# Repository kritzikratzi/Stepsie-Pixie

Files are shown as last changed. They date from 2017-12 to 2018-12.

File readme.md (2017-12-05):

<font color="red">WIP, please come back in a few weeks/months</font>

# Stepsie Pixie (WIP!)

This is a small project that combines: 

* stepper motor (to move your camera)
* relais (to trigger virtually any SLR camera)
* display+buttons (to adjust a few settings in place)
* esp8266 (as a controller, if things go well it'll also offer a web-ui)

The repository contains the code for the Arduino IDE and (soon) the eagle layout for making the board.

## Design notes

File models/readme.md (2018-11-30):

# 3D Models

**As always, work in progress**

This folder contains the 3d print models for stepsie pixie. You will need blender, openscad and a slicer tool of your choice to generate the STL and gcode files needed for printing. 

## Stepper to lego attachment 

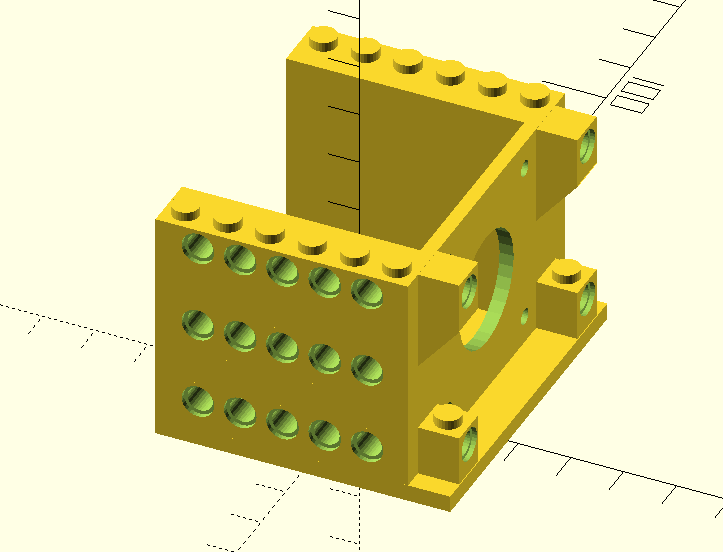
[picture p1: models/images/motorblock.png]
<br>
See `motorblock.scad`

A little attachement for a Nema-17 stepper with lots of oppertunities to connect to lego. 

## Tripod to lego attachment

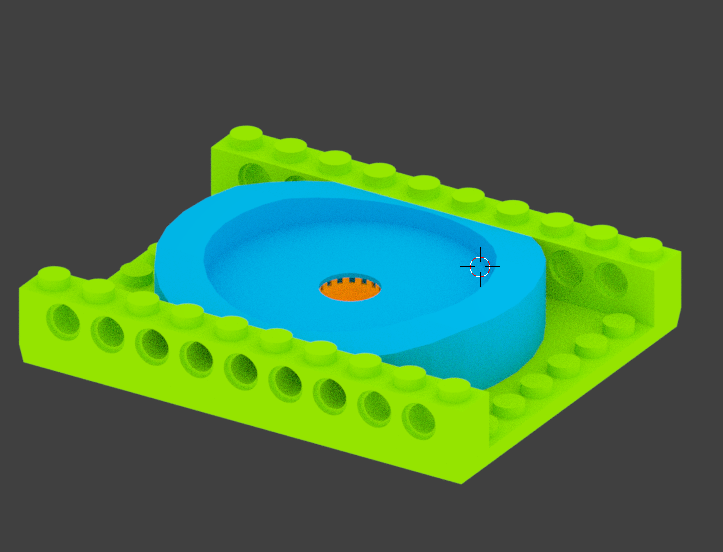
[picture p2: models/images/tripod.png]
<br>
See `tripod.6.blend`

A lego for an incredibly cheap but incredibly well built ball head tripod. 
https://www.amazon.de/Andoer-Kamera-Kugelkopf-Schnellwechselplatte-Schraube/dp/B00JSJXH3Q/

This also requires a large tripod screw to hold the tripod in place. 

## PCB Box (no lego attachment yet)

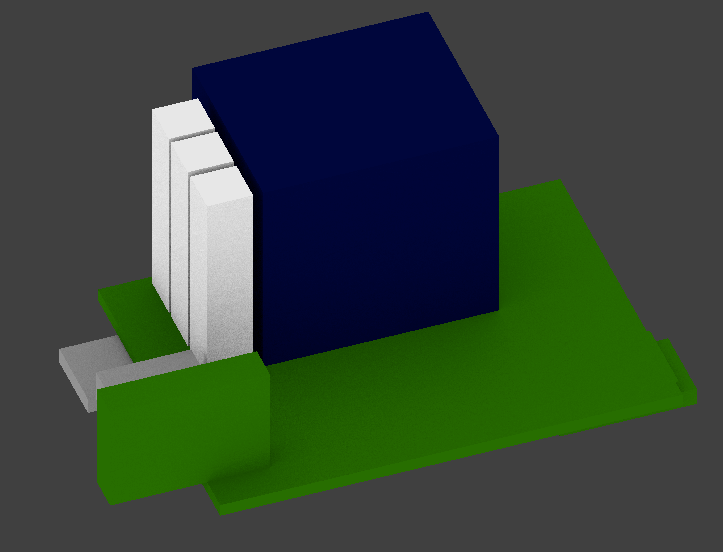
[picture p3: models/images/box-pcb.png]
<br>
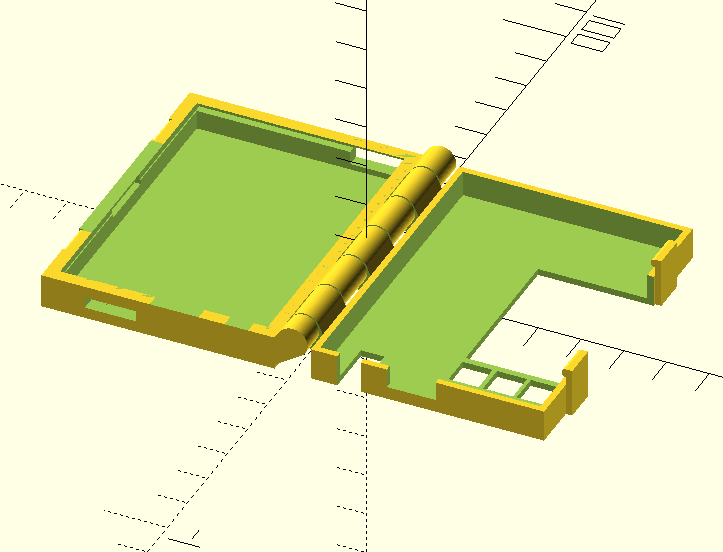
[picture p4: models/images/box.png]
<br>
* `Hinged_Box_asymtest.scad` The actual box. Print this! 
* `case.1.blend` Coarse layout of the PCB. I use this to make quick 2-layer prints to see if it fits in the real world. 
* `hinge-pcb.stl` STL export of the blender file. This is used in the openscad file to make lots of holes. 

## Library Credits

* Openscad lego library: https://github.com/cfinke/LEGO.scad (MIT License)
* Openscad hinged box: https://www.thingiverse.com/thing:82533 (CC-BY-NC)

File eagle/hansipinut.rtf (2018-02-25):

Buttons
D5
D6
D7

Stepper
D3 =
D4
D8
D9

D10 => Trigger WRONG

PINS vom OLED ESP:
d3 =IO0
d4 = IO2
d8 = IO15
d9 = rxd = GPIO3
d10 = txd = GPIO1

up=GPIO13 auf gnd = D7
down = GPIO12 auf gnd = D6
press = GPIO14 = D5

Wir brauchen:
- 3 Inputs f. Buttons
- 4 Out für Stepper
- 1 Out ENA
- 1 Out Trigger

Probieren wir mal:
GPIO0 = S1 => D3 OK
GPIO2 = S2 => D4? => Darf offenbar kein IN sein… => D10 mit int. Pullup OK
ADC = S3 OK

Dann bleiben:
GPIO12 = D6 = Stepper
GPIO13 = D7 = Stepper
GPIO3 = RXD = D9 = Stepper = Wie vorher
GPIO1 = TXD = D10 = Relais verkehrt rum => machma mal D4 draus
GPIO14 = D5 = Stepper
GPIO15 = D8 den machma zu Stepper enable

stepper alt zu neu
D3 = D5 = rxd hat pullup!
D4 = D6 = gpio12
D8 = D7 = GPIO13
D9 = D9 gleich = 4a?

ADC als Input verwenden????
txd darf nicht pulldown@boot

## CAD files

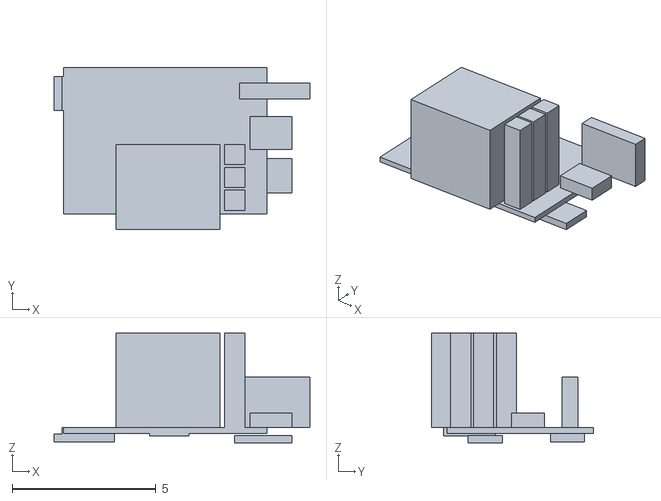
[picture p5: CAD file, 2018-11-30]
models/hinge-pcb.stl
8.92 x 5.63 x 3.83

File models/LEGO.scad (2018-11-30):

/**
 * Derived from http://www.thingiverse.com/thing:5699
 *
 * LEGO®, the LEGO® logo, the Brick, DUPLO®, and MINDSTORMS® are trademarks of the LEGO® Group. ©2012 The LEGO® Group.
 */

/* [General] */

// Width of the block, in studs
block_width = 2;

// Length of the block, in studs
block_length = 6;

// Height of the block. A ratio of "1" is a standard LEGO brick height; a ratio of "1/3" is a standard LEGO plate height; "1/2" is a standard DUPLO plate.
block_height_ratio = 1; // [.33333333333:1/3, .5:1/2, 1:1, 2:2, 3:3, 4:4, 5:5, 6:6, 7:7, 8:8, 9:9, 10:10]

// What type of block should this be? For type-specific options, see the "Wings," "Slopes," "Curves", and "Baseplates" tabs.
block_type = "brick"; // [brick:Brick, tile:Tile, wing:Wing, slope:Slope, curve:Curve, baseplate:Baseplate]

// What brand of block should this be? LEGO for regular LEGO bricks, Duplo for the toddler-focused larger bricks.
block_brand = "lego"; // [lego:LEGO, duplo:DUPLO]

// What stud type do you want? Hollow studs allow rods to be pushed into the stud.
stud_type = "solid"; // [solid:Solid, hollow:Hollow]

// Should the block include round horizontal holes like the Technics LEGO bricks have?
technic_holes = "no"; // [no:No, yes:Yes]

// Should the block include vertical cross-shaped axle holes?
vertical_axle_holes = "no"; // [no:No, yes:Yes]

/* [Wings] */

// What type of wing? Full is suitable for the front of a plane, left/right are for the left/right of a plane.
wing_type = "full"; // [full:Full, left:Left, right:Right]

// The number of studs across the end of the wing. If block_width is odd, this needs to be odd, and the same for even.
wing_end_width = 2;

// The length of the rectangular portion of the wing, in studs.
wing_base_length = 3;

// Should the wing edges be notched to accept studs below?
wing_stud_notches = "yes"; // [yes:Yes, no:No]

/* [Slopes] */

// How many rows of studs should be left before the slope?
slope_stud_rows = 1;

// How much vertical height should be left at the end of the slope? e.g, a value of zero means the slope reaches the bottom of the block. A value of 1 means that for a block with height 2, the slope reaches halfway down the block.
slope_end_height = 0;

/* [Curves] */

// How many rows of studs should be left before the curve?
curve_stud_rows = 5;

// Should the curve be convex or concave?
curve_type = "concave"; // [concave:Concave, convex:Convex]

// How much vertical height should be left at the end of the curve? e.g, a value of zero means the curve reaches the bottom of the block. A value of 1 means that for a block with height 2, the curve reaches halfway down the block.
curve_end_height = 0;

/* [Baseplates] */

// If you want a roadway, how wide should it be (in studs)? A roadway is a smooth (non-studded) section of a baseplate.
roadway_width = 0;

// How long should the roadway be?
roadway_length = 0;

// Where should the roadway start (x-value)? A value of zero puts the roadway at the far left side of the plate.
roadway_x = 0;

// Where should the roadway start (y-value)? A value of zero puts the roadway at the front of the plate.
roadway_y = 0;

/* [SNOT] */

// SNOT means Studs Not On Top -- bricks with alternative stud configurations.
// Put studs on the top and buttom?
dual_sided = "no"; // [no:No, yes:Yes]

// Instead of both sides having studs, both sides can have no studs.
dual_bottom = "no"; // [no:No, yes:Yes]

/* [Printer-Specific] */

// Should extra reinforcement be included to make printing on an FDM printer easier? Ignored for tiles, since they're printed upside-down and don't need the reinforcement. Recommended for block heights less than 1 or for Duplo bricks. 
use_reinforcement = "no"; // [no:No, yes:Yes]

// If your printer prints the blocks correctly except for the stud diameter, use this variable to resize just the studs for your printer. A value of 1.05 will print the studs 105% wider than standard.
stud_rescale=1.05;
//stud_rescale = 1.0475 * 1; // Orion Delta, T-Glase
//stud_rescale = 1.022 * 1; // Orion Delta, ABS

// Print tiles upside down.
translate([0, 0, (block_type == "tile" ? block_height_ratio * block_height : 0)]) rotate([0, (block_type == "tile" ? 180 : 0), 0]) {
    block(
        width=block_width,
        length=block_length,
        height=block_height_ratio,
        type=block_type,
        brand=block_brand,
        stud_type=stud_type,
        horizontal_holes=(technic_holes=="yes"),
        vertical_axle_holes=(vertical_axle_holes=="yes"),
        reinforcement=(use_reinforcement=="yes"),
        wing_type=wing_type,
        wing_end_width=wing_end_width,
        wing_base_length=wing_base_length,
        stud_notches=(wing_stud_notches=="yes"),
        slope_stud_rows=slope_stud_rows,
        slope_end_height=slope_end_height,
        curve_stud_rows=curve_stud_rows,
        curve_type=curve_type,
        curve_end_height=curve_end_height,
        roadway_width=roadway_width,
        roadway_length=roadway_length,
        roadway_x=roadway_x,
        roadway_y=roadway_y,
        stud_rescale=stud_rescale,
        dual_sided=(dual_sided=="yes"),
        dual_bottom=(dual_bottom=="yes")
    );
}

module block(
    width=1,
    length=2,
    height=1,
    type="brick",
    brand="lego",
    stud_type="solid",
    horizontal_holes=false,
    vertical_axle_holes=false,
    reinforcement=false,
    wing_type="full",
    wing_end_width=2,
    wing_base_length=2,
    stud_notches=false,
    slope_stud_rows=1,
    slope_end_height=0,
    curve_stud_rows=1,
    curve_type="concave",
    curve_end_height=0,
    roadway_width=0,
    roadway_length=0,
    roadway_x=0,
    roadway_y=0,
    stud_rescale=stud_rescale,
    dual_sided=false,
    dual_bottom=false
    ) {
    post_wall_thickness = (brand == "lego" ? 0.85 : 1);
    wall_thickness=(brand == "lego" ? 1.45 : 1.5);
    stud_diameter=(brand == "lego" ? 4.85 : 9.35);
    hollow_stud_inner_diameter = (brand == "lego" ? 3.1 : 6.7);
    stud_height=(brand == "lego" ? 1.8 : 4.4);
    stud_spacing=(brand == "lego" ? 8 : 8 * 2);
    block_height=(brand == "lego" ? (type == "baseplate" ? 1.3 : 9.6) : 9.6 * 2);
    pin_diameter=(brand == "lego" ? 3 : 3 * 2);
    post_diameter=(brand == "lego" ? 6.5 : 13.2);
    cylinder_precision=(brand == "lego" ? 0.1 : 0.05);
    reinforcing_width = (brand == "lego" ? 0.7 : 1);

    spline_length = (brand == "lego" ? 0.25 : 1.7);
    spline_thickness = (brand == "lego" ? 0.7 : 1.3);

    horizontal_hole_diameter = (brand == "lego" ? 4.8 : 4.8 * 2);
    horizontal_hole_z_offset = (brand == "lego" ? 5.8 : 5.8 * 2);
    horizontal_hole_bevel_diameter = (brand == "lego" ? 6.2 : 6.2 * 2);
    horizontal_hole_bevel_depth = (brand == "lego" ? 0.9 : 0.9 * 1.5 / 1.2 );

    roof_thickness = (type == "baseplate" || dual_sided ? block_height * height : 1 * 1);

    // Brand-independent measurements.
    axle_spline_width = 2.0;
    axle_diameter = 5 * 1;
    wall_play = 0.1 * 1;
    horizontal_hole_wall_thickness = 1 * 1;

    // Ensure that width is always less than or equal to length.
//hansi:
    real_width = width;
    real_length = length;

//    real_width = (type == "wing" ? width : min(width, length) );
//    real_length = (type == "wing" ? length : max(width, length) );
    real_height = max((type == "baseplate" ? 1 : 1/3), height);

    // Ensure that the wing end width is even if the width is even, odd if odd, and a reasonable value.
    real_wing_end_width = (wing_type == "full"
        ?
        min(real_width - 2, ((real_width % 2 == 0) ? 
            (max(2, (
                wing_end_width % 2 == 0 ?
                (wing_end_width)
                :
                (wing_end_width-1)
            )))
            :
            (max(1, (
                wing_end_width % 2 == 0 ?
                (wing_end_width-1)
                :
                (wing_end_width)
            )))
        ))
        :
        (min(real_width-1, max(1, wing_end_width))) // Half-wing
    );

    // Ensure that the base length is a reasonable value.
    real_wing_base_length = min(real_length-1, max(1, wing_base_length)) + 1; // +1 because the angle starts before the last stud.
        
    // Validate all the rest of the arguments.
    real_slope_end_height = max(0, min(real_height - 1/3, slope_end_height));
    real_slope_stud_rows = min(real_length - 1, slope_stud_rows);
    real_curve_stud_rows = max(0, curve_stud_rows);
    real_curve_type = (curve_type == "convex" ? "convex" : "concave");
    real_curve_end_height = max(0, min(real_height - 1/3, curve_end_height));
    real_horizontal_holes = horizontal_holes && ((type == "baseplate" && real_height >= 8) || real_height >= 1) && !dual_sided;
    real_vertical_axle_holes = vertical_axle_holes && real_width > 1;
    real_reinforcement = reinforcement && type != "baseplate" && type != "tile" && !dual_sided;
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

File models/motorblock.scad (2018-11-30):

use <LEGO.scad>;

le=8;
lh=9.6;

rotate([0, 0, 180]) union() {
    scale([le,le,lh]){
        translate([-3+1/6,-0.015,3+1/6]) difference(){
            cube([1/3,6+0.03,4+1/3],true);
            scale([1/le,1/le,1/lh]) union(){
                rotate([0,90,0]) cylinder(h=10, d=22, center=true, $fn=32);
                rotate([0,90,0]) translate([ 41/2-5,-41/2+5,0]) cylinder(h=10, d=3, center=true, $fn=32);
                rotate([0,90,0]) translate([-41/2+5, 41/2-5,0]) cylinder(h=10, d=3, center=true, $fn=32);
                rotate([0,90,0]) translate([-41/2+5,-41/2+5,0]) cylinder(h=10, d=3, center=true, $fn=32);
                rotate([0,90,0]) translate([ 41/2-5, 41/2-5,0]) cylinder(h=10, d=3, center=true, $fn=32);
            }
        }
        
         translate([-3,3.5-0.025,3+1/3]) rotate([-90,180,90]) color("orange")  prism(1-0.025, 1, 1);
         translate([-3,-2.54+0.015,3+1/3]) rotate([-90,180,90]) color("orange")  prism(1-0.025, 1, 1);
    };
    
    delta=3*le-42/2;
    length=(6-1/3)*le-0.2;
    translate([(-3+1/3)*le,42/2,lh]) color("black") cube([length,delta,(4+1/3)*lh], center=false);
    translate([(-3+1/3)*le,-42/2-delta-0.2,lh]) color("black") cube([length,delta,(4+1/3)*lh], center=false);
    
    color( "blue" ) place(0, -0.5, 2/3) uncenter(0, 0) block(
      width=8,
      length=7,
      roadway_width=8,
      roadway_length=7,
      height=1/3,
      reinforcement="yes"
     );

    color( "red" ) place(3, -3.5+0.02, 1) uncenter(0, 0)  rotate([0,0,90]) block(
      width=1,
      length=1,
      height=1,
      horizontal_holes=true,
      reinforcement="yes"
);
    color( "red" ) place(3, -3.5+0.02, 4+1/3) uncenter(0, 0)  rotate([0,0,90]) block(
      width=1,
      length=1,
      height=1,
      horizontal_holes=true,
      reinforcement="yes",
      roadway_width=1, 
      roadway_length=1
     );
    color( "red" ) place(-3, -3.5+0.02, 1) uncenter(0, 0) rotate([0,0,90]) block(
      width=1,
      length=1,
      height=1,
      horizontal_holes=true,
      reinforcement="yes"
     );
    color( "red" ) place(-3, -3.5+0.02, +4+1/3) uncenter(0, 0) rotate([0,0,90]) block(
      width=1,
      length=1,
      height=1,
      horizontal_holes=true,
      reinforcement="yes",
      roadway_width=1, 
      roadway_length=1
     );

    
    for(b=[0,1]){
        place(-7*b,0) union(){
            for(x=[0:2]){
                color( "green") place(3.5, 0, 1+x*5/3) uncenter(0, 0) block(
                    width=1,
                    length=6,
                    height=1,
                    horizontal_holes=true
                );
            }
            for(y=[0:1]){
                color( "blue" ) place(3.5, 0, 2+5/3*y) uncenter(0, 0) block(
                    width=1,
                    length=6,
                    height=2/3,
                    horizontal_holes=true
                );
            }
        }
    };
   // }
}

   module prism(l, w, h){
       polyhedron(
               points=[[0,0,0], [l,0,0], [l,w,0], [0,w,0], [0,w,h], [l,w,h]],
               faces=[[0,1,2,3],[5,4,3,2],[0,4,5,1],[0,3,4],[5,2,1]]
               );
       }

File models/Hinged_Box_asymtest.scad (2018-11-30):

$fn = 100;
width = 54.5;
height = 7;
asym=1;
depth = 74.5;
wallThickness = 1.5;
hingeOuter = 6.5;
hingeInner = 3.5;
hingeInnerSlop = .4;
hingeFingerSlop = .4;
fingerLength = hingeOuter/1.65;
fingerSize = 12;
topFingerSize = fingerSize;
pos = -depth/2;
latchWidth = 8;
lift=0;
z = 0;

top_final_ani();
bottom_final();
//top();
//pcb();
//bottom(); 

module top_final_ani(){
    translate([0,0,height]){
        r = max(0, min(1, ($t*1.4-0.2)));
        rotate([0,-r*180,0]){
            translate([0,0,-height]){
                top_final(); 
            }
        }
    }
}
module top_final(){
    difference(){
        top(); 
        translate([0,0,height+0*asym]){
            rotate([0,180,0]){
                translate([0,0,-height]){
                    pcb(); 
                }
            }
        }
   }
} 

module bottom_final(){
    difference(){
        bottom(); 
        pcb();
    }
}

module pcb(){
    translate([-31,-0.85,5+asym]){
        rotate([0,0,-90]){
            scale([10,10,10]){
                color([1,0,0])
                import("hinge-pcb.stl", convexity=5);
            }
        }
    }
}


module bottom() {
    h2=height+asym;
	union() {
		// main box and cutout
		difference() {
			translate([-width - fingerLength, -depth/2, 0]) {
				cube([width,depth,h2]);
			}
            
/*			translate([(-width - fingerLength) + wallThickness, -depth/2 + wallThickness, wallThickness]) {
				cube([width - (wallThickness * 2), depth - (wallThickness * 2), height]);
			}*/
            
            translate([(-width - fingerLength) + wallThickness*2, -depth/2 + wallThickness*2, wallThickness]) {
				cube([width - (wallThickness * 4), depth - (wallThickness * 4), height]);
			}


             for(i = [-1 : 2: 1]){
                 dy = i*depth*0.3;
                 translate([0,dy,0]){

                    // latch cutout
                    translate([-width - fingerLength - 0.05, (-latchWidth/2) - (hingeFingerSlop/2), wallThickness]) {
                        cube([wallThickness/2 + .1, latchWidth + hingeFingerSlop, height]);
                    }
                }
            }
			
		}

         for(i = [-1 : 2: 1]){
             dy = i*depth*0.3;
             translate([0,dy,0]){

                //latch cylinder
                difference() {
                    translate([-width - fingerLength + (wallThickness/1.5), -latchWidth/2, h2 - 1]) {
                        rotate([-90,0,0]) {
                            color([0,1,0]) cylinder(r = 1, h = latchWidth);
                        }
                    }
                    // front wall wipe
                    translate([-width - fingerLength+1, -depth/2,0]) {
                        color([1,0,0]) cube([5,depth,h2]);
                    }
                }
            }
        }
        
		difference() {
			hull() {
				translate([0,-depth/2,height]) {
					rotate([-90,0,0]) {
						cylinder(r = hingeOuter/2, h = depth);
					}
				}
				translate([-fingerLength - .1, -depth/2,height - hingeOuter]){
					cube([.1,depth,hingeOuter]);
				}
				translate([-fingerLength, -depth/2,height-.1]){
					cube([fingerLength,depth,.1]);
				}
				translate([0, -depth/2,height]){
					rotate([0,45,0]) {
						cube([hingeOuter/2,depth,.01]);
					}
				}
			}
			// finger cutouts

			for  (i = [-depth/2 + fingerSize:fingerSize*2:depth/2]) {
				translate([-fingerLength,i - (fingerSize/2) - (hingeFingerSlop/2),0]) {
					cube([fingerLength*2,fingerSize + hingeFingerSlop,height*2]);
				}
			}
		}

		// center rod
		translate([0, -depth/2, height]) {
			rotate([-90,0,0]) {
				cylinder(r = hingeInner /2, h = depth);
			}
		}
	}
}

module top() {
    h2=height-asym;
	union() {
		difference() {
			translate([fingerLength, -depth/2, 0]) {
				cube([width,depth,h2 - .5]);
			}
	
			translate([fingerLength + wallThickness, -depth/2 + wallThickness, wallThickness]) {
				cube([width - (wallThickness * 2), depth - (wallThickness * 2), h2]);
			}

			
		}

		//latch
         for(i = [-1 : 2: 1]){
             dy = i*depth*0.3;
             translate([0,dy,0]){
                translate([width + fingerLength - 0*wallThickness - 0*1.5, (-latchWidth/2), 0]) {
                    color([0,1,0])
                    cube([1.5, latchWidth, h2 - .5 + 4]);
                }
                translate([width + fingerLength - 0*wallThickness, -latchWidth/2, h2 - .5 + 3]) {
                    rotate([-90,0,0]) {
                        cylinder(r = 1, h = latchWidth);
                    }
                }
            }
        }

		difference() {
			hull() {
				translate([0,-depth/2,height]) {
					rotate([-90,0,0]) {
						cylinder(r = hingeOuter/2, h = depth);
					}
				}
				translate([fingerLength, -depth/2,height - hingeOuter - .5]){
					cube([.1,depth,hingeOuter - .5]);
				}
				translate([-fingerLength/2, -depth/2,height-.1]){
					cube([fingerLength,depth,.1]);
				}
				translate([0, -depth/2,height]){
					rotate([0,45,0]) {
						cube([hingeOuter/2,depth,.01]);
					}
				}
			}
			// finger cutouts
			for  (i = [-depth/2:fingerSize*2:depth/2 + fingerSize]) {
				translate([-fingerLength,i - (fingerSize/2) - (hingeFingerSlop/2),0]) {
					cube([fingerLength*2,fingerSize + hingeFingerSlop,height*2]);
				}
				if (depth/2 - i < (fingerSize * 1.5)) {
					translate([-fingerLength,i - (fingerSize/2) - (hingeFingerSlop/2),0]) {
						cube([fingerLength*2,depth,height*2]);
					}
				}
			}

			// center cutout
			translate([0, -depth/2, height]) {
				rotate([-90,0,0]) {
					cylinder(r = hingeInner /2 + hingeInnerSlop, h = depth);
				}
			}
		}
	}
    
    dh=h2-0.5-wallThickness;
    translate([width/2,0,wallThickness]){
        color([1,0,0]) translate([24,-31.5,0]) cylinder(h=dh,r=3);
        color([1,0,1]) translate([24, 31.5,0]) cylinder(h=dh,r=3);
        color([0,1,0]) translate([-14,-19,0]) cylinder(h=dh,r=3);
        color([0,0,1]) translate([-14, 19,0]) cylinder(h=dh,r=3);
    }
}

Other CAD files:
models/case.1.blend
models/tripod6.blend

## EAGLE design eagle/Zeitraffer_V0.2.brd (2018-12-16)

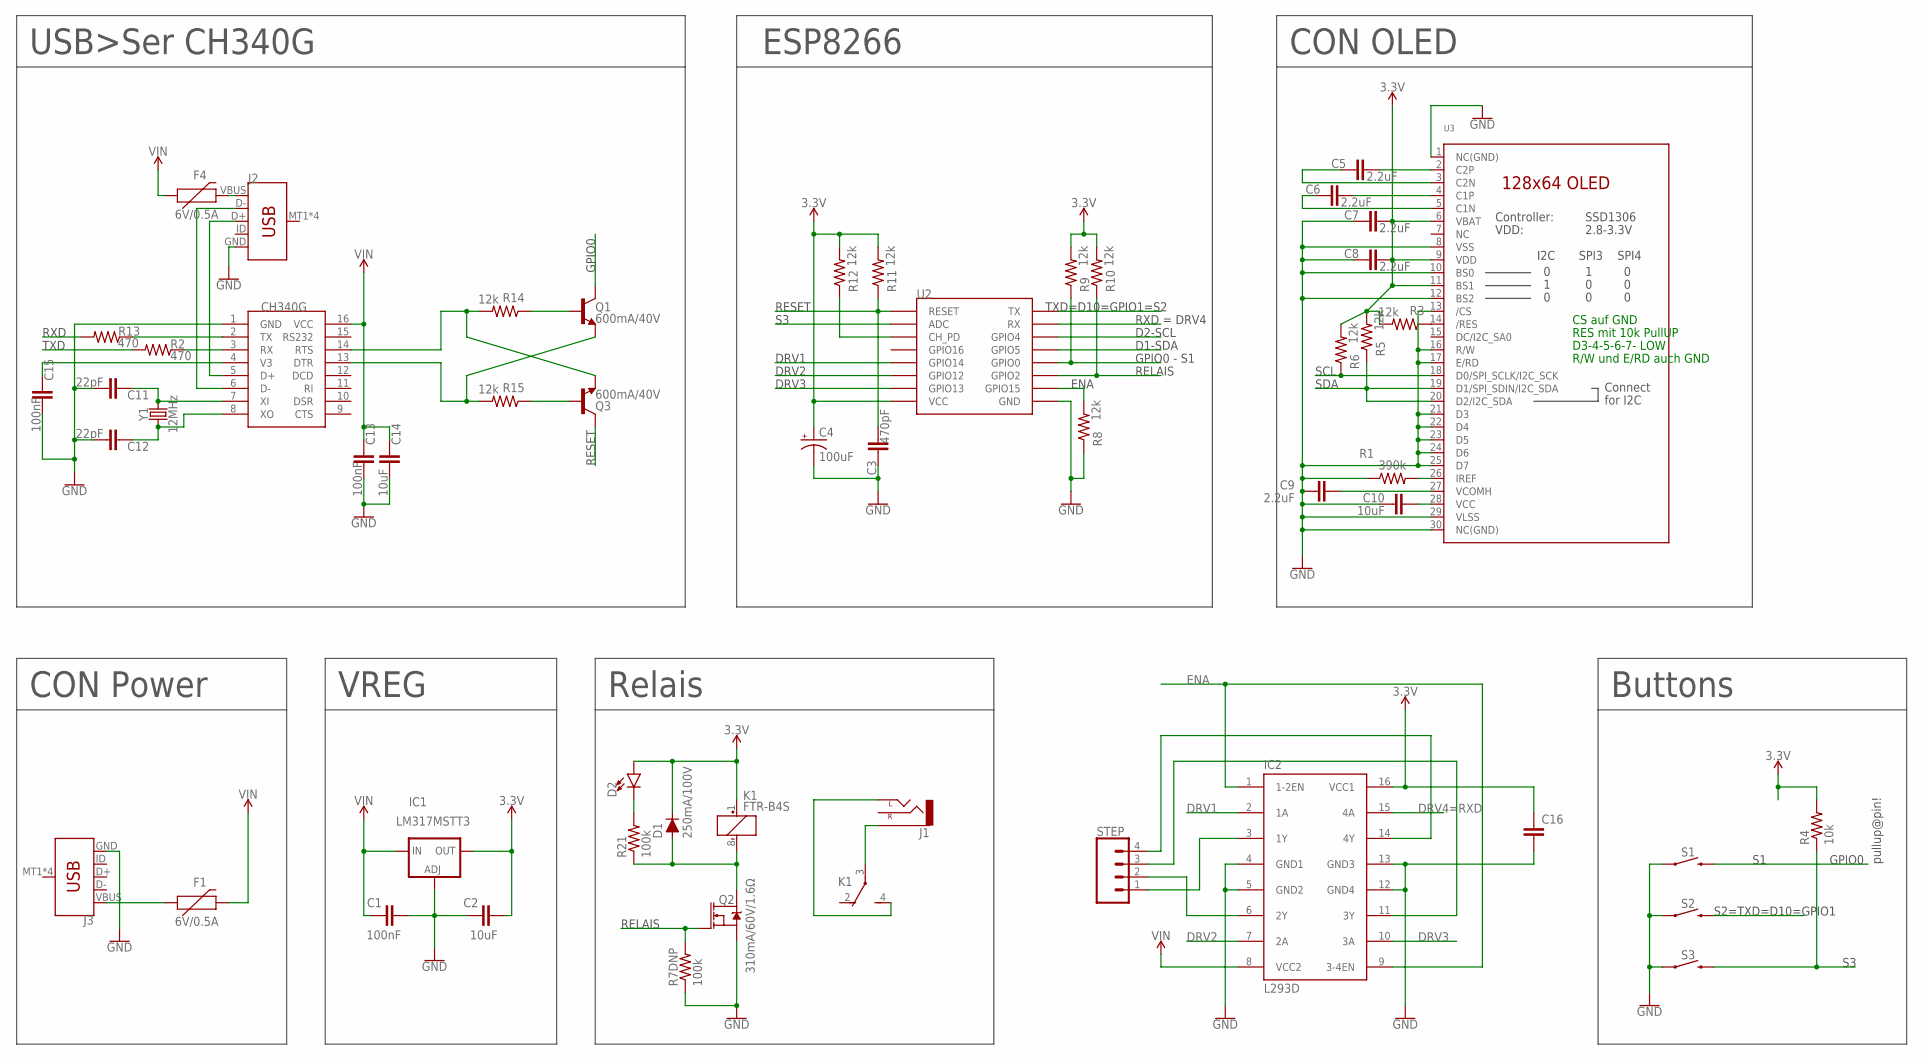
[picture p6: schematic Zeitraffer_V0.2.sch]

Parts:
C1, C13, C15: 100nF; 0805
C2, C10, C14: 10uF; 0805
C3: 470pF; 0805
C4: 100uF; EIA7343
C5, C6, C7, C8, C9: 2.2uF; 0805
C11, C12: 22pF; 0805
C16: C-EUC0805; C0805
D1: 250mA/100V; SOD-323
D2: LED1206-BOTTOM; LED-1206-BOTTOM
F1, F4: 6V/0.5A; 1206
IC1: LM317MSTT3; SOT223
IC2: L293D; DIL16
J1: AUDIO_JACK_2.5MM_2.5MM; STEREOJACK2.5MM_STEREOJACK2.5MM
J2, J3: USB_MICRO-B_SMT; USB-MICROB
K1: FTR-B4S
Q1, Q3: 600mA/40V; SOT23-3
Q2: 310mA/60V/1.6Ω; SOT323
R1: 390k; 0805
R2, R13: 470; 0603
R3, R5, R6, R8, R9, R10, R11, R12, R14, R15: 12k; R0805
R4: 10k; R0805
R7DNP, R21: 100k; R0805
S1, S2, S3: MOMENTARY-SWITCH-SPST-PTH-6.0MM; TACTILE_SWITCH_PTH_6.0MM
STEP: CONN_04JST-PTH; JST-4-PTH
U2: ESP12SMD; ESP12-SMD
U3: DISP_OLED_UG-2864HSWEG01; UG-2864HSWEG01_1.3_WRAPAROUND
U$2: CH340G; SOIC16
Y1: 12MHz; CRYSTAL-SMD-5X3.2-4PAD

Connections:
3.3V: C2.2, C4.A (+), C7.2, C8.2, C16.1, D1.C, D2.A, IC1.4 (OUT), IC2.16 (VCC1), K1.1 (+), R3.2, R4.2, R5.2, R6.2, R9.2, R10.2, R11.2, R12.2, U2.VCC, U3.6 (VBAT), U3.9 (VDD), U3.11 (BS1)
DRV1: IC2.2 (1A), U2.GPIO14
DRV2: IC2.7 (2A), U2.GPIO12
DRV3: IC2.10 (3A), U2.GPIO13
ENA: IC2.1 (1-2EN), IC2.9 (3-4EN), R8.2, U2.GPIO15
GND: C1.2, C2.1, C3.1, C4.C (-), C7.1, C8.1, C9.1, C10.1, C11.2, C12.2, C13.2, C14.2, C15.2, C16.2, IC1.1 (ADJ), IC2.4 (GND1), IC2.5 (GND2), IC2.12 (GND4), IC2.13 (GND3), J2.GND, J3.GND, Q2.2 (S), R1.1, R7DNP.1, R8.1, S1.1, S2.1, S3.1, U2.GND, U3.1 (NC(GND)), U3.8 (VSS), U3.10 (BS0), U3.12 (BS2), U3.13 (/CS), U3.16 (R/W), U3.17 (E/RD), U3.21 (D3), U3.22 (D4), U3.23 (D5), U3.24 (D6), U3.25 (D7), U3.29 (VLSS), U3.30 (NC(GND)), U$2.1 (GND)
GPIO0: Q1.3 (C), R9.1, S1.3 (2), U2.GPIO0
unnamed: F1.1, J3.VBUS
unnamed: J1.RING1 (SLEEVE), K1.3
unnamed: D1.A, K1.8 (-), Q2.3 (D), R21.1
unnamed: J1.SHIELD (LEFT), K1.4 (S)
unnamed: C5.2, U3.2 (C2P)
unnamed: C6.2, U3.4 (C1P)
unnamed: C5.1, U3.3 (C2N)
unnamed: C6.1, U3.5 (C1N)
unnamed: R1.2, U3.26 (IREF)
unnamed: C9.2, U3.27 (VCOMH)
unnamed: C10.2, U3.28 (VCC)
unnamed: R3.1, U3.14 (/RES)
unnamed: C11.1, U$2.7 (XI), Y1.3 (2)
unnamed: R12.1, U2.CH_PD
unnamed: C12.1, U$2.8 (XO), Y1.1
unnamed: J2.D+, U$2.5 (D+)
unnamed: J2.D-, U$2.6 (D-)
unnamed: Q3.2 (E), R14.2, U$2.14 (RTS)
unnamed: Q1.2 (E), R15.2, U$2.13 (DTR)
unnamed: R13.1, U$2.2 (TX)
unnamed: R2.1, U$2.3 (RX)
unnamed: C15.1, U$2.4 (V3)
unnamed: Q3.1 (B), R15.1
unnamed: Q1.1 (B), R14.1
unnamed: IC2.3 (1Y), STEP.1
unnamed: IC2.6 (2Y), STEP.2
unnamed: F4.2, J2.VBUS
unnamed: D2.C, R21.2
unnamed: IC2.14 (4Y), STEP.4
unnamed: IC2.11 (3Y), STEP.3
RELAIS: Q2.1 (G), R7DNP.2, R10.1, U2.GPIO2
RESET: C3.2, Q3.3 (C), R11.1, U2.RESET
RXD: IC2.15 (4A), R13.2, U2.RXD0 (RX)
S3: R4.1, S3.3 (2), U2.ADC
SCL: R6.1, U2.GPIO4, U3.18 (D0/SPI_SCLK/I2C_SCK)
SDA: R5.1, U2.GPIO5, U3.19 (D1/SPI_SDIN/I2C_SDA), U3.20 (D2/I2C_SDA)
TXD: R2.2, S2.3 (2), U2.TXD0 (TX)
VIN: C1.1, C13.1, C14.1, F1.2, F4.1, IC1.3 (IN), IC2.8 (VCC2), U$2.16 (VCC)

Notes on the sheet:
SCL
SDA
CON OLED
VREG
S2=TXD=D10=GPIO1
Buttons
CON Power
RELAIS
Relais
TXD=D10=GPIO1=S2
RXD = DRV4
GPIO0 - S1
RESET
D1-SDA
D2-SCL
GPIO0
pullup@pin!
DRV2
DRV3
DRV1
ESP8266
TXD
RXD
USB>Ser CH340G
ENA
DRV4=RXD
CS auf GND
RES mit 10k PullUP
D3-4-5-6-7- LOW
R/W und E/RD auch GND

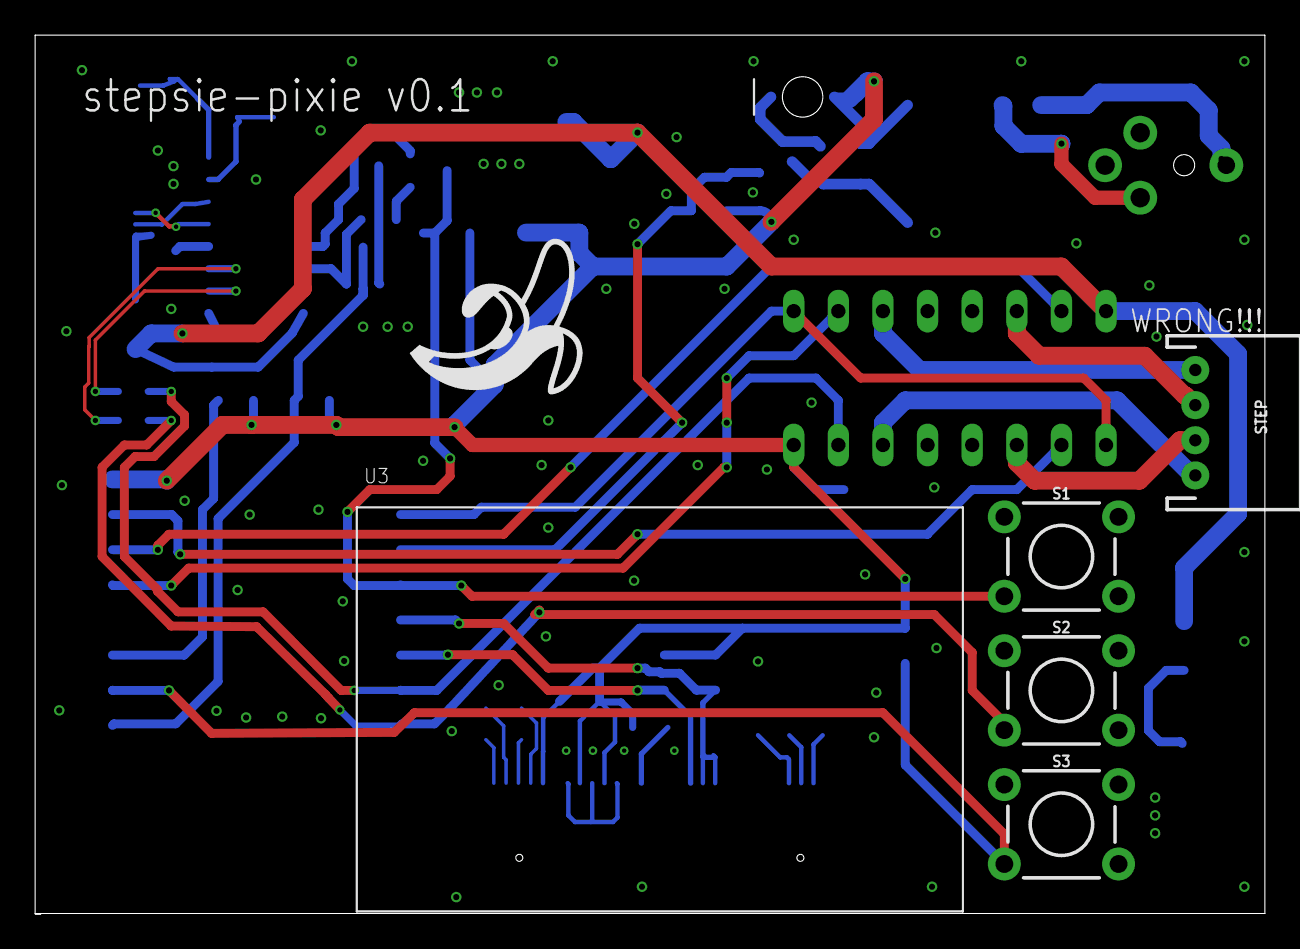
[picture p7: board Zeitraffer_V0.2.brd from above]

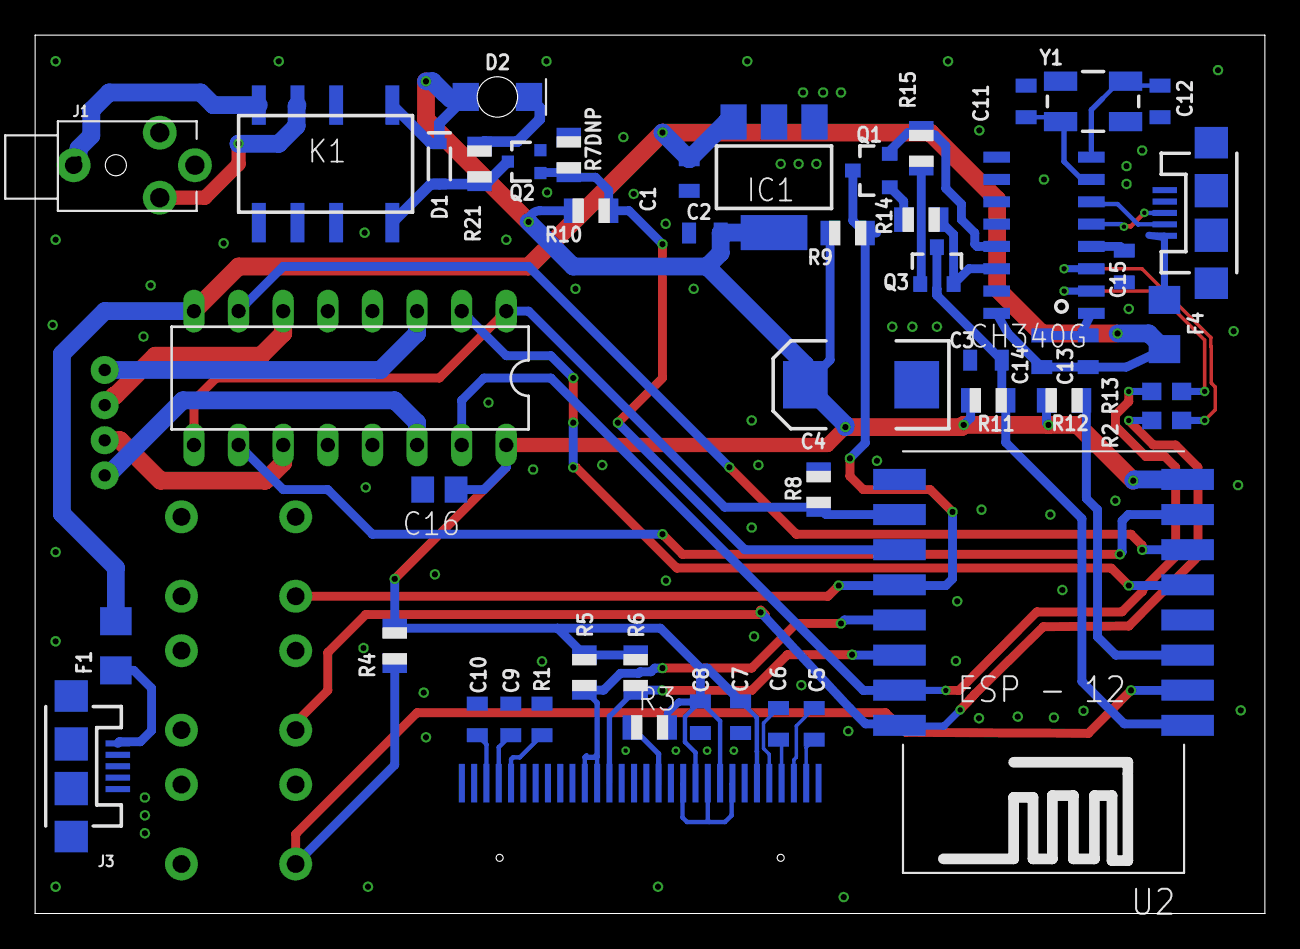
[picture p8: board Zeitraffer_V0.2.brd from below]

Board: 2 copper layers, 70.0 x 50.0 mm, 53 parts (48 on the bottom side), 45 nets.

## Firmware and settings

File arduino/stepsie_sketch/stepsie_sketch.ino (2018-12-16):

//stephan

#define DISPLAY_SDA 4
#define DISPLAY_SCL 5

#define BTN1_GPIO 0
#define BTN2_GPIO 1
#define BTN3_GPIO 16



#define STEPPER_M1 14
#define STEPPER_M2 12
#define STEPPER_M3 13
#define STEPPER_M4 3

#define TRIGGER_PIN 2
#define ENABLE_PIN 15

#define DISPLAY_ROTATE 1

// ai-thinker variant
// btn1 on pin "rx"
/*#define DISPLAY_SDA 5
#define DISPLAY_SCL 4

#define BTN1_GPIO 3
#define BTN2_GPIO 1
#define BTN3_GPIO 0

// // 14=D5, 12=D6, 13=D7, 15=D8
#define STEPPER_M1 14
#define STEPPER_M2 13
#define STEPPER_M3 12 
#define STEPPER_M4 15

#define TRIGGER_PIN D0
#define DISPLAY_ROTATE 1

*/

//WIFI Configuration (also see server tab)
#define ACCESSPOINT_SSID "controller-1"
#define ACCESSPOINT_PASS "youkidouki"

#include <TimeLib.h>
#include <Wire.h>
#include "SH1106Wire.h"
#include <Stepper.h>
//h#include <HalfStepper.h>
#include <EEPROM.h>

// Initialize the OLED display using Wire library
SH1106Wire display(0x3c, DISPLAY_SDA, DISPLAY_SCL); // 5=D1, 4=D2

const int stepsPerRevolution = 200;  // change this to fit the number of steps per revolution
Stepper stepper(stepsPerRevolution, STEPPER_M1, STEPPER_M2, STEPPER_M3, STEPPER_M4); 


#include "OLEDDisplayUi.h"
OLEDDisplayUi ui ( &display );

void setup() {
  pinMode(TRIGGER_PIN, OUTPUT); 
  pinMode(ENABLE_PIN, OUTPUT); 


  digitalWrite(ENABLE_PIN, LOW); 
//  ESP.wdtDisable();
//  ESP.wdtEnable(WDTO_8S);

//  EEPROM.begin(512); 
    setupMenu(); 
//  funnySetup(); 
  
//  setupServer(); 

  
  //pinMode(BTN1_GPIO, INPUT_PULLUP); 
  pinMode(BTN1_GPIO, INPUT_PULLUP);
  pinMode(BTN2_GPIO, INPUT_PULLUP); 
  //pinMode(BTN3_GPIO, INPUT_PULLUP); 
}

void loop() {
//  updateServer(); 
  updateMenu(); 
  drawMenu(); 
//  delay(1);
//  yield(); 

//  funnyLoop(); 
}

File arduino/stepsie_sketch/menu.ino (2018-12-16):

const int ee_numSteps = 0; // 0..3 
const int ee_stepSpeed = 4;  // 4..7
const int ee_interval = 8; // 8..11
const int ee_record = -1;  // not stored!

#include <vector>


Value numSteps{10, ee_numSteps,-10000,10000}; 
Value stepSpeed{10, ee_stepSpeed,1,60}; 
Value interval{5, ee_interval,1,10000}; 
Value record{0, ee_record,0,0}; 


std::vector<Value*> values({&numSteps, &stepSpeed, &interval, &record}); 

// eeprom address to store settings


Value * editValue = &numSteps; 

Button btnUp([](){ return (bool)!digitalRead(BTN1_GPIO);}); 
Button btnDown([](){ return (bool)!digitalRead(BTN2_GPIO);}); 
Button btnNext([](){ return analogRead(A0) < 512;}); 

typedef enum State{
  STEP_INIT,
  STEP_DRIVE, 
  STEP_PICTURE
} State; 

State state = STEP_INIT; 
unsigned long stepStartMillis = 0; 
unsigned long stepRemainingMillis = 0; 
unsigned long stepRemainingPct = 0; 
unsigned long nextLoopTime = 0; 

int stepsDriven = 0; 
bool shouldTakePicture = false; 

void setupMenu(){
  // Initialising the UI will init the display too.
  display.init();
  delay(100); 
  display.clear(); 
  display.init(); 
  delay(100); 
  
  if(DISPLAY_ROTATE){
    display.flipScreenVertically();
  }
  display.setFont(ArialMT_Plain_10);

  display.clear();

  display.setTextAlignment(TEXT_ALIGN_LEFT);
  display.drawString(5, 0, "It's timelapse time! ...");

  display.display();


  for( auto value : values){
    value->load(); 
  }

  record = false; 
}

void updateMenu(){
  stepRemainingPct = random(100); 
  
  unsigned long now = millis(); 
  btnNext.update(now); 
  btnUp.update(now); 
  btnDown.update(now); 
  for(auto value : values){
    value->update(now); 
  }
  if(btnNext.triggered()){
    if(btnNext.pressedLongerThan(5000)){
      // reset to defaults! 
      for(auto value : values){
        value->reset(); 
      }
    }
    
    if(editValue == &numSteps ) editValue = &stepSpeed; 
    else if(editValue == &stepSpeed ) editValue = &interval; 
    else if(editValue == &interval ) editValue = &record; 
    else editValue = &numSteps; 
  }

  auto incValue = [](Button & btn, Value & value, int increment){
    if(btn.triggered() && btn.pressedLongerThan(5000)){
      increment *= 10;
    }
    value = value + increment; 
  }; 
  

  if(btnUp.triggered()){
    incValue(btnUp, *editValue, +1); 
  }
  
  if(btnDown.triggered()){
    incValue(btnDown, *editValue, -1); 
  }
  
  record = ((record%2)+2)%2; 
  digitalWrite(ENABLE_PIN, record?HIGH:LOW); 

  if(record){
    unsigned long T = std::max(1,std::max(interval.get(), -interval.get()))*1000; 
    if(nextLoopTime == 0) nextLoopTime = now + T; 
    
    switch(state){
      case STEP_INIT: {
        stepStartMillis = T; 
        state = STEP_DRIVE; 
        stepsDriven = 0; 
        break; 
      }
      case STEP_DRIVE: {
        bool reverse = numSteps<0; 
        int numStepsPos = reverse?-numSteps:numSteps; 
        int motorDuration = constrain((numStepsPos*1000)/stepSpeed/4/*?*/, 1,std::max(numStepsPos*50,(int)T-500)); // 500
        int stepsWanted = constrain(map(T-(nextLoopTime-now), 0,motorDuration,  0,numStepsPos), 0, numStepsPos); 
        int driveNow = std::max(0,stepsWanted-stepsDriven);
        stepper.setSpeed(std::max(10,(int)stepSpeed));
        driveNow = std::min(driveNow,10); // never more than 10 steps ^
        stepper.step(reverse?-driveNow:driveNow); 
        stepsDriven += driveNow; 
        
        if(now>nextLoopTime-500){
          //drive remaining steps
          state = STEP_PICTURE; 
          shouldTakePicture = true; 
        }
        break; 
      }
      case STEP_PICTURE:
        if(shouldTakePicture){
          digitalWrite(TRIGGER_PIN, HIGH); 
          delay(50); 
          digitalWrite(TRIGGER_PIN, LOW); 
          triggerServer(); 
          shouldTakePicture = false; 
        }
        
        if(now>=nextLoopTime){
          state = STEP_INIT; 
          nextLoopTime += T; 
        }
        break; 
    }

    stepRemainingMillis = nextLoopTime<now?0:(nextLoopTime-now); 
    stepRemainingPct = std::min(100,(int)(100-stepRemainingMillis*100/T)); 
  }
  else{
    state = STEP_INIT; 
    nextLoopTime = 0; 
    stepRemainingPct = 0; 
    stepRemainingMillis = 0; 
  }
}


void drawMenu(){
  display.clear();

  display.setTextAlignment(TEXT_ALIGN_LEFT);
  display.drawString(5, 0, "Steps");
  display.drawString(5,10, "Speed"); 
  display.drawString(5,20, "Interval"); 
  display.drawString(5,54, record?"Run ...":"Stopped"); 

  if(editValue == &numSteps) display.drawString(0,2, "*"); 
  display.drawString(50, 0, String(numSteps)); 
  if(editValue == &stepSpeed) display.drawString(0,12, "*"); 
  display.drawString(50,10, String(stepSpeed)); 
  if(editValue == &interval) display.drawString(0,22, "*"); 
  display.drawString(50,20, String(interval)); 
  if(editValue == &record) display.drawString(0,56, "*"); 


  if(record){
    display.drawProgressBar(50, 55, 50, 8, std::min(100,(int)stepRemainingPct));
  }
  
  display.drawString(80,20,"sec"); 

  display.drawFastImage(118,0, 8, 8, icon_tri_up); 
  display.drawFastImage(118,30, 8, 8, icon_tri_down); 
  display.drawFastImage(118,52, 8, 8, icon_tri_next); 
  
  display.display();  
}

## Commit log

2018-02-25 added eagle files
    [Adafruit_1.3_128x64_OLED.brd, Adafruit_1.3_128x64_OLED.sch, Zeitraffer_V0.1.brd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]
2018-02-25 removed unnecessary adafruit files
    [Adafruit_1.3_128x64_OLED.brd, Adafruit_1.3_128x64_OLED.sch]
2018-02-26 final touchups generated gerber
    [Zeitraffer_V0.1.brd]
2018-11-30 added 3d models
    [Hinged_Box_asymtest.scad, LEGO.scad, case.1.blend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]
2018-12-16 arduino: updated pins so it matches the eagle layout, added icons for +/-/next, disable motor while inactive
2018-12-16 added new board version
    [Zeitraffer_V0.2.brd, Zeitraffer_V0.2.sch]

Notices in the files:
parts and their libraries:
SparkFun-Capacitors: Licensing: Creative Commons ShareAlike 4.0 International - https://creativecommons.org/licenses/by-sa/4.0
